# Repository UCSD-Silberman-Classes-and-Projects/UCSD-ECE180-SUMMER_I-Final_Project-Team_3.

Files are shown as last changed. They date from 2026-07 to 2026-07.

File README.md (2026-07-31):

# <div align="center">AI Music Instrument & Vocal Removal Device</div>
### <div align="center">ECE 180 Final Project</div>
#### <div align="center">Team #3 — Summer Session I 2026</div>

**Photos:** [Front View](https://drive.google.com/file/d/1DdtovpZk14N7O1HgtoTwd-P9sjlYPKgB/view?usp=sharing) | [Side View](https://drive.google.com/file/d/1why-yrY0hsEtVmtkVGPhBQCBYVUqeQCW/view?usp=sharing) | [Back View](https://drive.google.com/file/d/10IjpwqsGlS_dRstfoKWQImvOjWGpgrZu/view?usp=sharing)
<!-- TODO: for photos to display inline instead of as links, upload them directly into the repo (e.g. docs/media/) and swap these links for ![Front View](docs/media/front.jpg) etc. -->

## Table of Contents
1. [Team Members](#team-members)
2. [Abstract](#abstract)
3. [What We Promised](#what-we-promised)
4. [Accomplishments](#accomplishments)
5. [Challenges](#challenges)
6. [Final Project Video](#final-project-video)
7. [How It Works](#how-it-works)
8. [Hardware](#hardware)
9. [Repo Contents](#repo-contents)
10. [Setup / Usage](#setup--usage)
11. [Troubleshooting](#troubleshooting)
12. [Restoring the Project on a New Board](#restoring-the-project-on-a-new-board)
13. [If We Had Another Week](#if-we-had-another-week)
14. [Acknowledgements](#acknowledgements)
15. [Contacts](#contacts)

<hr>

## Team Members

Eli Carsenti - Electrical & Computer Engineering

Jason Salazar Rios - Electrical & Computer Engineering

Vadim Keenan - Electrical & Computer Engineering

<hr>

## Abstract

A karaoke-style audio stem separation system that runs entirely on the Arduino Uno Q. Load a song from a USB flash drive, and the board automatically detects it and uses a Demucs-based ML model to split it into vocal, drums, bass, and other stems. Physical buttons let you mute/unmute individual stems on the fly — sing along without the vocals, drop the drums, isolate the bass — then finalize a real mixed-down track and play it back over AUX with adjustable volume and a live status display.

<hr>

## What We Promised

### Must Have
- [x] Upload song
- [x] Play back song w/ vocals removed
- [x] Physical controls (switches/buttons)
- [x] Display showing progress and status
- [x] Aux output for headphones and speakers
- [x] Adjustable volume
- [x] Pause and play
- [ ] Rewind and fast forward

### Nice to Have
- [x] Remove acoustic/electric guitar, bass, piano, drums
- [ ] Play parts in lower volume instead of only muting
- [ ] Advanced display (load time, song timer, progress bar)
- [x] Labeled controls
- [x] Soldered build in a nice 3D-printed case

<hr>

## Accomplishments

**Design Evolution**
- Initial version: fully webpage-based — upload, stem separation, playback, mute feedback
- Final version: moved entirely to hardware — no webpage upload flow; USB ingestion, physical buttons, potentiometer, TFT display, AUX output

**Core Pipeline (Final Version)**
- Song dropped on a USB flash drive is auto-detected by `demucs_server.py`'s USB watcher thread and separated with Demucs 4.1.0
- `main.py` polls the server's `/status` endpoint and downloads all four stems (vocal, drums, bass, other) once separation completes
- Buttons mute/unmute individual stems; pressing **Finalize** builds a real mixed-down track by summing the non-muted stems' waveforms and normalizing if needed
- Play/pause plays the finalized mix via `aplay`; the potentiometer sets system volume via `amixer`
- A 5-line ST7735 TFT display (driven directly over SPI with a hand-rolled font) shows upload status, which stems are kept/muted, finalize status, and play status — each line owned independently so different events never overwrite each other

**Hardware & Controls**
- Physical buttons for stem muting, finalize, and pause/play
- Potentiometer for adjustable volume
- SPI TFT display working, showing live status
- Flash drive file reading integrated with playback
- Soldered build housed in a 3D-printed case

**AI Model**
- Iterated past an early overtrained model (dataset too large → too small dataset) by switching to a bigger Demucs model, landing on an "optimal" result
- New trained model successfully combined with the Arduino circuit

<hr>

## Challenges

| Issue | Why | Fix |
|---|---|---|
| Rewind / fast-forward on device | Implementing it in App Lab would've required overhauling how audio is handled there; the needed library was too large and wouldn't install properly | Kept this feature in the Web UI version instead — drag the bar/point to jump to any timestamp in the song |
| Web UI file size limit | The way App Lab ingests files has this limit built in; it could not be fixed or worked around | Switched to USB flash drive upload (the original design) to remove the file size limit entirely |
| AUX port power | Direct connection wasn't getting sufficient power to play audio | Ran the AUX cord through a USB hub (via a USB-C converter) instead — also freed up room on the Arduino for the flash drive and power |
| Model training | An early fine-tuning attempt overtrained on a too-small dataset | Switched to a bigger Demucs model and retrained, landing on an "optimal" result |

<hr>

## Final Project Video

- [Demo Video 1 — before stem separation](https://drive.google.com/file/d/1QZgK7SNFArip6ig8x3jpaVQxmAbc0eBg/view?usp=sharing)
- [Demo Video 2 — after stem separation](https://drive.google.com/file/d/1xyiZW-JPjazSeEFnDOGOuh60KiNtbXhP/view?usp=sharing)

<hr>

## How It Works

The system splits work across the Uno Q's two processors:

- **MCU side (STM32):** Reads button and potentiometer input, drives the ST7735 TFT display directly over SPI, and communicates with the Linux side over Bridge RPC.
- **MPU side (Debian Linux):** Runs a Python backend (`main.py`) plus a separate Demucs server (`demucs_server.py`) for stem separation and playback via `aplay`/`amixer`.

### Workflow

1. Load a song onto a USB flash drive and plug it into the board. A background thread in `demucs_server.py` polls for a new song every 5 seconds and starts separation automatically — no manual upload step.
2. The server runs Demucs 4.1.0 as a subprocess, splitting the song into **vocals**, **drums**, **bass**, and **other**, and exposes progress via `/status`.
3. `main.py` polls `/status`; once complete, it downloads each stem from `/download/<stem>`.
4. Physical buttons mute/unmute each stem individually:
   - `VOCAL` → pin 2
   - `BASS` → pin 3
   - `DRUMS` → pin 4
   - `OTHER` → pin 5
   - `FINALIZE` → pin 6
   - `PLAY/PAUSE` → pin 7
5. Pressing **Finalize** builds a real mix from the kept stems (sums the waveforms, normalizes on clipping) and saves it to a temp WAV.
6. **Play/Pause** plays that finalized mix via `aplay -D hw:0,0`; the potentiometer (analog pin A0) sets system volume via `amixer`.
7. The ST7735 TFT display shows five independent status lines: upload/processing status (with a spinner), which stems are kept, which are muted, finalize status, and play status.
8. Audio plays out over AUX, routed through a USB hub via a USB-C converter.

<hr>

## Hardware

- Arduino Uno Q
- USB DAC for AUX audio output
- ST7735 SPI TFT display (128×160)
- Potentiometer (volume control, analog pin A0)
- USB flash drive (song input)
- 3D-printed enclosure

See [Side View](https://drive.google.com/file/d/1why-yrY0hsEtVmtkVGPhBQCBYVUqeQCW/view?usp=sharing) and [Back View](https://drive.google.com/file/d/10IjpwqsGlS_dRstfoKWQImvOjWGpgrZu/view?usp=sharing) above for the internal wiring layout.
<!-- TODO: add a dedicated circuit/wiring diagram if you have one, separate from the enclosure photos -->

<hr>

## Repo Contents

| File | Description |
|---|---|
| `app.yaml` | App Lab project metadata (Bricks used, etc.) |
| `python/main.py` | Core application logic: polls the Demucs server, downloads stems, handles button-driven mute/finalize/play state, builds the final mixed-down track, and pushes status to the display. |
| `python/requirements.txt` | Python dependencies (`numpy`, `soundfile`). |
| `sketch/sketch.ino` | STM32 firmware — reads all six buttons and the volume pot, drives the ST7735 TFT display over SPI, and exposes button states to Python via `Bridge.provide_safe`. |
| `sketch/sketch.yaml` | Sketch configuration. |
| `assets/index.html`, `assets/app.js`, `assets/style.css` | Browser-side status mirror (not an upload UI) — reflects stem mute state and finalized-mix playback. |
| `demucs_server.py` *(Linux-side, separate from this App Lab project)* | Flask server that watches the USB drive for a new song, runs Demucs 4.1.0, and exposes `/status` and `/download/<stem>` endpoints. |
| `usb_song_test.py` *(Linux-side)* | Small test/debug script — reads `/home/arduino/current_song.txt` and confirms whether the referenced song file actually exists on the USB drive. |
| `usb_demucs_test.py` *(Linux-side)* | Small test/debug script — runs Demucs directly on a hardcoded USB song path (`/mnt/usb/sound.wav`) to verify Demucs works standalone, outside the full server pipeline. |
| `local_demucs_test.py` *(Linux-side)* | Test/debug script for running Demucs on a local (non-USB) file. |
<!-- TODO: add local_demucs_test.py to the repo — referenced in the setup guide but not yet uploaded -->

<hr>

## Setup / Usage

### 1. Set up the Python virtual environment (Linux side of the Uno Q)

```bash
python3 -m venv ~/demucs-env
source ~/demucs-env/bin/activate
pip install --upgrade pip
pip install demucs
pip install torch torchaudio
pip install soundfile numpy scipy pygame requests
```

### 2. Create the required directories

```bash
mkdir ~/uploads
mkdir ~/separated
mkdir ~/usb_import
```

### 3. Copy the Linux-side scripts

Copy `demucs_server.py`, `usb_song_test.py`, `usb_demucs_test.py`, and `local_demucs_test.py` into the Arduino user's home directory (`/home/arduino/`).

### 4. Prepare the USB flash drive

Format it as **FAT32** and place one supported audio file on it (`.wav`, `.mp3`, or `.flac`).

### 5. Flash the sketch and deploy the App Lab project

Flash `sketch/sketch.ino` to the STM32 side via App Lab, then import/deploy the App Lab project (`app.yaml`, `python/`, `assets/`) to the Uno Q.

### 6. Run it

Start the Demucs server (`python demucs_server.py`) and launch the App Lab app. Insert the USB drive — separation starts automatically. Use the buttons to mute/unmute stems, press Finalize to build the mix, and Play/Pause to listen.

<hr>

## Troubleshooting

**USB not detected**
- Run `lsblk` to confirm the drive shows up.
- Reinsert the drive or try another one.
- Confirm it's formatted as FAT32.
- If it still doesn't auto-mount: `sudo mkdir -p /mnt/usb && sudo mount /dev/sda1 /mnt/usb` (replace `sda1` with the correct device from `lsblk`).

**No stems created**
- Check `find ~/separated` for output.
- Confirm the audio file is readable and Demucs is installed inside `demucs-env`.
- Check the terminal for Python errors.

**Display frozen**
- Restart the App Lab application.
- Verify the display's ribbon/SPI connection is firmly seated.
- Confirm `set_display()` is still being called from `poll_buttons()`.

<hr>

## Restoring the Project on a New Board

**Download the backup:** [unoq_project_backup.tar.gz (Google Drive)](https://drive.google.com/file/d/1VhwF-bbFnjsz2kegRBSiR_RpDgHN-fi_/view?usp=sharing)

If you need to set up the project on a fresh Uno Q from this backup (containing `ArduinoApps/`, `demucs-env/`, `demucs_server.py`, `requirements.txt`, `uploads/`, and `separated/`):

1. Connect the Uno Q and get it on the same network as your computer.
2. Find the board's IP with `hostname -I`.
3. Copy the backup over: `scp unoq_project_backup.tar.gz arduino@<ARDUINO_IP>:/home/arduino/`
4. SSH in, extract it (`tar -xzvf unoq_project_backup.tar.gz`), and restore the files (`cp -r ~/backup_files/* ~/`).
5. Activate the venv and confirm Demucs is installed: `source ~/demucs-env/bin/activate && demucs --version`
6. Start the server: `python demucs_server.py`
7. Reopen this App Lab project and upload it to the board.

<hr>

## If We Had Another Week

**Trained Demucs Model**
- Implement our own trained version of the Demucs model instead of the preexisting version
- Allows for guitar and piano separation as well
- Make sure it works without internet or computer connection

**Per-Stem Volume Control**
- Tackle this Nice to Have: adjustable volume for each individual stem, not just an all-out mute
- Lets users blend stems in rather than only choosing to include or remove them entirely

<hr>

## Acknowledgements

Thank you to our Professor, TAs, and classmates!

<hr>

## Contacts

- Vadim Keenan - vkeenan@ucsd.edu
- Eli Carsenti - ecarsenti@ucsd.edu
- Jason Salazar Rios - jasalazarrios@ucsd.edu

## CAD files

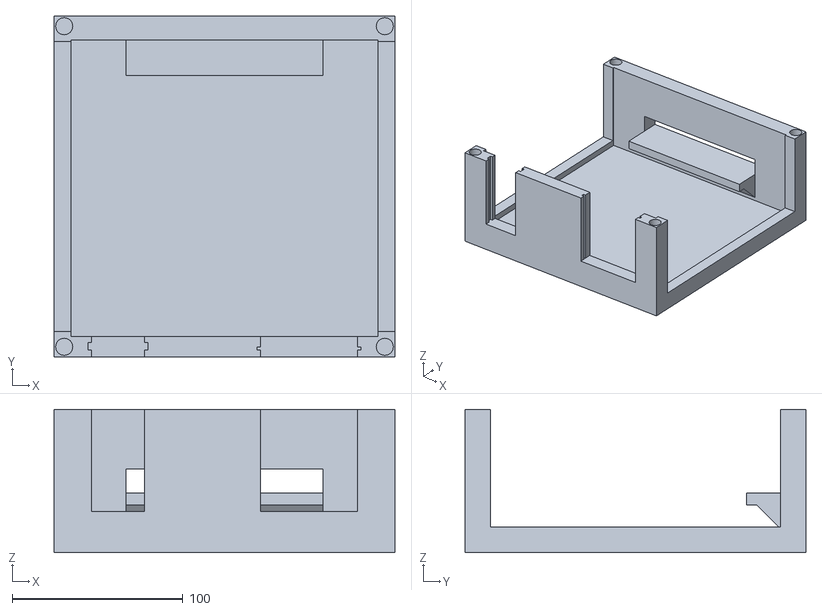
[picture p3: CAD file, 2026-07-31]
models/MAINCASE.stl
200.0 x 200.0 x 84.0

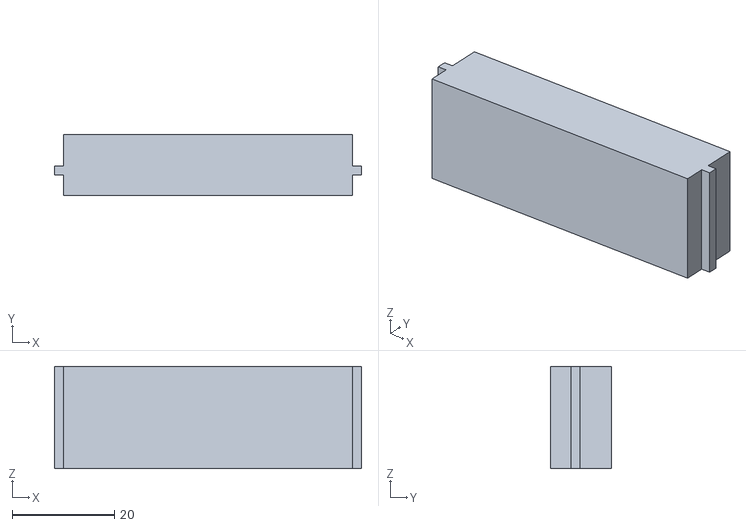
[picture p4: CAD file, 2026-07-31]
models/SOLDERBOARD_FILL.stl
60.0 x 12.0 x 20.0

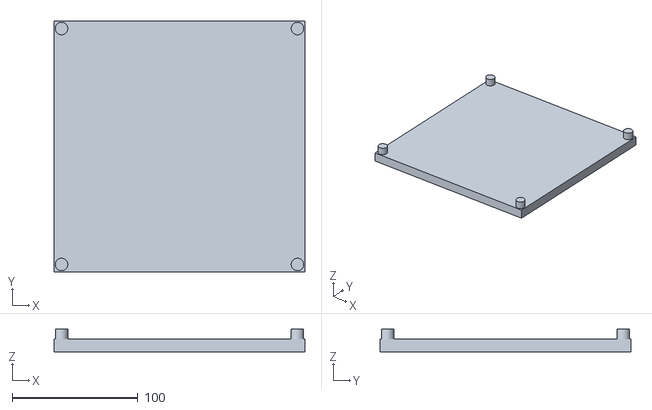
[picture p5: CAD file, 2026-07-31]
models/CASETOP.stl
200.0 x 200.0 x 18.0

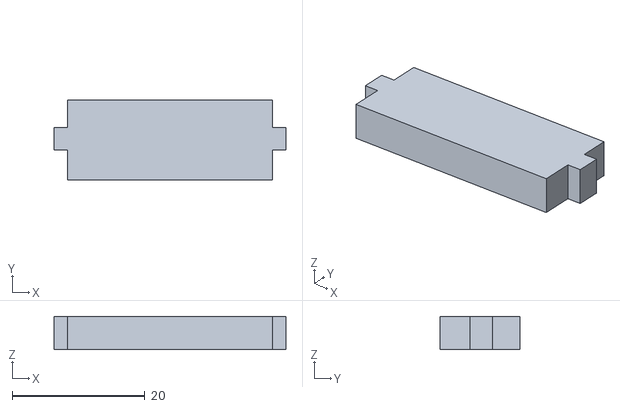
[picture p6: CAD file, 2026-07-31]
models/DISPLAY_FILL.stl
34.9 x 12.0 x 5.00

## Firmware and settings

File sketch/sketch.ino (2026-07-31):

#include <Arduino.h>
#include <Arduino_RouterBridge.h>
#include <SPI.h>

// --- PIN DEFINITIONS ---
const int VOCAL_BUTTON     = 2;
const int BASS_BUTTON      = 3;
const int DRUMS_BUTTON     = 4;
const int OTHER_BUTTON     = 5;
const int FINALIZE_BUTTON  = 6;
const int PLAYPAUSE_BUTTON = 7;
const int VOLUME_POT       = A0;

// TFT Display Pins (SPI)
#define TFT_CS   10
#define TFT_RST  8
#define TFT_DC   9

// --- ST7735 DISPLAY COMMANDS ---
#define ST7735_SWRESET 0x01
#define ST7735_SLPOUT  0x11
#define ST7735_COLMOD  0x3A
#define ST7735_DISPON  0x29
#define ST7735_CASET   0x2A
#define ST7735_RASET   0x2B
#define ST7735_RAMWR   0x2C

// Color definitions (16-bit RGB565)
#define COLOR_BLACK   0x0000
#define COLOR_GREEN   0x07E0
#define COLOR_WHITE   0xFFFF
#define COLOR_RED     0xF800
#define COLOR_YELLOW  0xFFE0

#define SCREEN_W 128
#define SCREEN_H 160

// --- 5x7 FONT TABLE (space, digits, A-Z, basic punctuation) ---
struct Glyph {
  char c;
  uint8_t bits[5];
};

const Glyph FONT[] = {
  {' ', {0x00,0x00,0x00,0x00,0x00}},
  {'!', {0x00,0x00,0x5F,0x00,0x00}},
  {',', {0x00,0x50,0x30,0x00,0x00}},
  {'.', {0x00,0x60,0x60,0x00,0x00}},
  {'-', {0x08,0x08,0x08,0x08,0x08}},
  {':', {0x00,0x36,0x36,0x00,0x00}},
  {'0', {0x3E,0x51,0x49,0x45,0x3E}},
  {'1', {0x00,0x42,0x7F,0x40,0x00}},
  {'2', {0x42,0x61,0x51,0x49,0x46}},
  {'3', {0x21,0x41,0x45,0x4B,0x31}},
  {'4', {0x18,0x14,0x12,0x7F,0x10}},
  {'5', {0x27,0x45,0x45,0x45,0x39}},
  {'6', {0x3C,0x4A,0x49,0x49,0x30}},
  {'7', {0x01,0x71,0x09,0x05,0x03}},
  {'8', {0x36,0x49,0x49,0x49,0x36}},
  {'9', {0x06,0x49,0x49,0x29,0x1E}},
  {'A', {0x7E,0x11,0x11,0x11,0x7E}},
  {'B', {0x7F,0x49,0x49,0x49,0x36}},
  {'C', {0x3E,0x41,0x41,0x41,0x22}},
  {'D', {0x7F,0x41,0x41,0x22,0x1C}},
  {'E', {0x7F,0x49,0x49,0x41,0x41}},
  {'F', {0x7F,0x09,0x09,0x01,0x01}},
  {'G', {0x3E,0x41,0x49,0x49,0x7A}},
  {'H', {0x7F,0x08,0x08,0x08,0x7F}},
  {'I', {0x00,0x41,0x7F,0x41,0x00}},
  {'J', {0x20,0x40,0x41,0x3F,0x01}},
  {'K', {0x7F,0x08,0x14,0x22,0x41}},
  {'L', {0x7F,0x40,0x40,0x40,0x40}},
  {'M', {0x7F,0x02,0x0C,0x02,0x7F}},
  {'N', {0x7F,0x04,0x08,0x10,0x7F}},
  {'O', {0x3E,0x41,0x41,0x41,0x3E}},
  {'P', {0x7F,0x09,0x09,0x09,0x06}},
  {'Q', {0x3E,0x41,0x51,0x21,0x5E}},
  {'R', {0x7F,0x09,0x19,0x29,0x46}},
  {'S', {0x46,0x49,0x49,0x49,0x31}},
  {'T', {0x01,0x01,0x7F,0x01,0x01}},
  {'U', {0x3F,0x40,0x40,0x40,0x3F}},
  {'V', {0x1F,0x20,0x40,0x20,0x1F}},
  {'W', {0x3F,0x40,0x38,0x40,0x3F}},
  {'X', {0x63,0x14,0x08,0x14,0x63}},
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
};
const int FONT_COUNT = sizeof(FONT) / sizeof(Glyph);

const uint8_t* findGlyph(char c) {
  if (c >= 'a' && c <= 'z') c -= 32;
  for (int i = 0; i < FONT_COUNT; i++) {
    if (FONT[i].c == c) return FONT[i].bits;
  }
  return FONT[0].bits;
}

// --- BUTTON STATE CALLBACKS FOR BRIDGE (Python polls these) ---
int vocal_state()    { return !digitalRead(VOCAL_BUTTON); }
int bass_state()     { return !digitalRead(BASS_BUTTON); }
int drums_state()    { return !digitalRead(DRUMS_BUTTON); }
int other_state()    { return !digitalRead(OTHER_BUTTON); }
int finalize_state() { return !digitalRead(FINALIZE_BUTTON); }

// --- DISPLAY HELPER FUNCTIONS ---
void writeCommand(uint8_t cmd) {
  digitalWrite(TFT_DC, LOW);
  digitalWrite(TFT_CS, LOW);
  SPI.transfer(cmd);
  digitalWrite(TFT_CS, HIGH);
}

void writeData(uint8_t data) {
  digitalWrite(TFT_DC, HIGH);
  digitalWrite(TFT_CS, LOW);
  SPI.transfer(data);
  digitalWrite(TFT_CS, HIGH);
}

void initDisplay() {
  digitalWrite(TFT_RST, HIGH); delay(50);
  digitalWrite(TFT_RST, LOW);  delay(50);
  digitalWrite(TFT_RST, HIGH); delay(150);

  writeCommand(ST7735_SWRESET); delay(150);
  writeCommand(ST7735_SLPOUT);  delay(150);
  writeCommand(ST7735_COLMOD);  writeData(0x05);
  writeCommand(ST7735_DISPON);  delay(100);
}

void fillRect(uint8_t x, uint8_t y, uint8_t w, uint8_t h, uint16_t color) {
  writeCommand(ST7735_CASET);
  writeData(0x00); writeData(x);
  writeData(0x00); writeData(x + w - 1);
  writeCommand(ST7735_RASET);
  writeData(0x00); writeData(y);
  writeData(0x00); writeData(y + h - 1);

  writeCommand(ST7735_RAMWR);
  digitalWrite(TFT_DC, HIGH);
  digitalWrite(TFT_CS, LOW);
  uint32_t total = (uint32_t)w * h;
  for (uint32_t i = 0; i < total; i++) {
    SPI.transfer(color >> 8);
    SPI.transfer(color & 0xFF);
  }
  digitalWrite(TFT_CS, HIGH);
}

void fillScreen(uint16_t color) {
  fillRect(0, 0, SCREEN_W, SCREEN_H, color);
}

void drawChar(uint8_t x, uint8_t y, const uint8_t* glyph, uint16_t color, uint8_t size) {
  for (uint8_t col = 0; col < 5; col++) {
    uint8_t line = glyph[col];
    for (uint8_t row = 0; row < 7; row++) {
      if (line & (1 << row)) {
        fillRect(x + col * size, y + row * size, size, size, color);
      }
    }
  }
}

void drawText(uint8_t x, uint8_t y, const char* text, uint16_t color, uint8_t size) {
  uint8_t cursor = x;
  uint8_t spacing = size;
  while (*text) {
    drawChar(cursor, y, findGlyph(*text), color, size);
    cursor += (5 * size) + spacing;
    text++;
  }
}

// --- FIVE-LINE STATUS DISPLAY -------------------------------------------
// Each row is independently owned by one piece of app state, so different
// events (upload, mute, finalize, play) can never overwrite each other.
#define ROW1_Y 8
#define ROW2_Y 32
#define ROW3_Y 56
#define ROW4_Y 80
#define ROW5_Y 104
#define ROW_H  20

bool set_display(String line1, String line2, String line3, String line4, String line5) {
  fillRect(0, ROW1_Y - 4, SCREEN_W, ROW_H, COLOR_BLACK);
  fillRect(0, ROW2_Y - 4, SCREEN_W, ROW_H, COLOR_BLACK);
  fillRect(0, ROW3_Y - 4, SCREEN_W, ROW_H, COLOR_BLACK);
  fillRect(0, ROW4_Y - 4, SCREEN_W, ROW_H, COLOR_BLACK);
  fillRect(0, ROW5_Y - 4, SCREEN_W, ROW_H, COLOR_BLACK);

  drawText(4, ROW1_Y, line1.c_str(), COLOR_GREEN, 1);
  drawText(4, ROW2_Y, line2.c_str(), COLOR_WHITE, 1);
  drawText(4, ROW3_Y, line3.c_str(), COLOR_WHITE, 1);
  drawText(4, ROW4_Y, line4.c_str(), COLOR_YELLOW, 1);
  drawText(4, ROW5_Y, line5.c_str(), COLOR_YELLOW, 1);

  return true;
}

// --- PLAYBACK CONTROL STATE (MCU pushes events to Python) ---
int lastVolume = -1;
bool lastPlayPauseState = HIGH;
unsigned long lastDebounceTime = 0;
const unsigned long debounceDelay = 50;

void setup() {
  Bridge.begin();

  pinMode(VOCAL_BUTTON, INPUT_PULLUP);
  pinMode(BASS_BUTTON, INPUT_PULLUP);
  pinMode(DRUMS_BUTTON, INPUT_PULLUP);
  pinMode(OTHER_BUTTON, INPUT_PULLUP);
  pinMode(FINALIZE_BUTTON, INPUT_PULLUP);
  pinMode(PLAYPAUSE_BUTTON, INPUT_PULLUP);

  Bridge.provide_safe("vocal_state", vocal_state);
  Bridge.provide_safe("bass_state", bass_state);
  Bridge.provide_safe("drums_state", drums_state);
  Bridge.provide_safe("other_state", other_state);
  Bridge.provide_safe("finalize_state", finalize_state);
  Bridge.provide_safe("set_display", set_display);

  pinMode(TFT_DC, OUTPUT);
  pinMode(TFT_RST, OUTPUT);
  pinMode(TFT_CS, OUTPUT);
  digitalWrite(TFT_CS, HIGH);

  SPI.begin();
  SPI.beginTransaction(SPISettings(12000000, MSBFIRST, SPI_MODE0));

  initDisplay();
  fillScreen(COLOR_BLACK);
  set_display("UPLOAD: WAITING", "KEPT: -", "MUTED: -", "FINAL: NO", "PLAY: NO");
}

void loop() {
  // -------------------------
  // Potentiometer volume
  // -------------------------
  int volume = map(analogRead(VOLUME_POT), 0, 1023, 0, 100);

  if (abs(volume - lastVolume) >= 2) {
    lastVolume = volume;
    Bridge.call("set_volume", String(volume));
  }

  // -------------------------
  // Play/Pause button
  // -------------------------
  int playPauseState = digitalRead(PLAYPAUSE_BUTTON);

  if (playPauseState == LOW && lastPlayPauseState == HIGH) {
    if (millis() - lastDebounceTime > debounceDelay) {
      Bridge.call("play_audio");
      lastDebounceTime = millis();
    }
  }
  lastPlayPauseState = playPauseState;

  delay(20);
  // Mute/finalize button states are read on-demand by Python via
  // Bridge.call(...) in poll_buttons() -- no polling needed here for those.
}

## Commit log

2026-07-31 Updated README.md again based on more current setup instructions
2026-07-31 Add 3D printed case STL files
    [CASETOP.stl, DISPLAY_FILL.stl, MAINCASE.stl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]
